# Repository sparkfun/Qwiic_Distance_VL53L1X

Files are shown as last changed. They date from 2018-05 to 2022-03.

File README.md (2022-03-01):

SparkFun Qwiic 4m Distance Sensor with VL53L1X
========================================

SparkFun Distance Sensor Breakout - 4 Meter, VL53L1X (Qwiic)

[*SparkFun Distance Sensor Breakout - 4 Meter, VL53L1X (Qwiic)(SEN-14722)*](https://www.sparkfun.com/products/14722)

The VL53L1X is the latest Time Of Flight (ToF) sensor to be released. It uses a VCSEL (vertical cavity surface emitting laser) to emit a class 1 IR laser and time the reflection to the target. What does all this mean? You can measure the distance to an object up to 4 meters away with millimeter resolution! That’s pretty incredible.

We’re far from done: The VL53L1X is a highly complex sensor with a multitude of options and configurations. We’ve written example sketches that allow you to read the distance, signal rate, and range status. Because ST has chosen not to release a complete datasheet we are forced to reverse engineer the interface from their example code and I2C data stream captures. If you’re into puzzles we could use your help to make the library better!

We’ve found the precision of the sensor to be 1mm but the accuracy is around +/-5mm.

SparkFun labored with love to create this code. Feel like supporting open source hardware? 
Buy a [breakout board](https://www.sparkfun.com/products/14722) from SparkFun!

Repository Contents
-------------------

* **/Documents** - Datasheet and User Manual
* **/Hardware** - Eagle design files (.brd, .sch)
* **/Production** - .brd files

Documentation
--------------
* **[Arduino Library](https://github.com/sparkfun/SparkFun_VL53L1X_Arduino_Library)** - Library for reading distance in millimeters, signal rate, status, etc.
* **[Hookup Guide](https://learn.sparkfun.com/tutorials/qwiic-distance-sensor-vl53l1x-vl53l4cd-hookup-guide)** - Basic hookup guide for the VL53L1X and VL53L4CD.

Product Versions
--------------
* **[SEN-14722](https://www.sparkfun.com/products/14722)** - SparkFun red version
* **[SPX-14667](https://www.sparkfun.com/products/14667)** - SparkX Version 

License Information
-------------------

This product is _**open source**_! 

Please review the LICENSE.md file for license information. 

If you have any questions or concerns on licensing, please contact techsupport@sparkfun.com.

Please use, reuse, and modify these files as you see fit. Please maintain attribution to SparkFun Electronics and release any derivative under the same license.

Distributed as-is; no warranty is given.

- Your friends at SparkFun.

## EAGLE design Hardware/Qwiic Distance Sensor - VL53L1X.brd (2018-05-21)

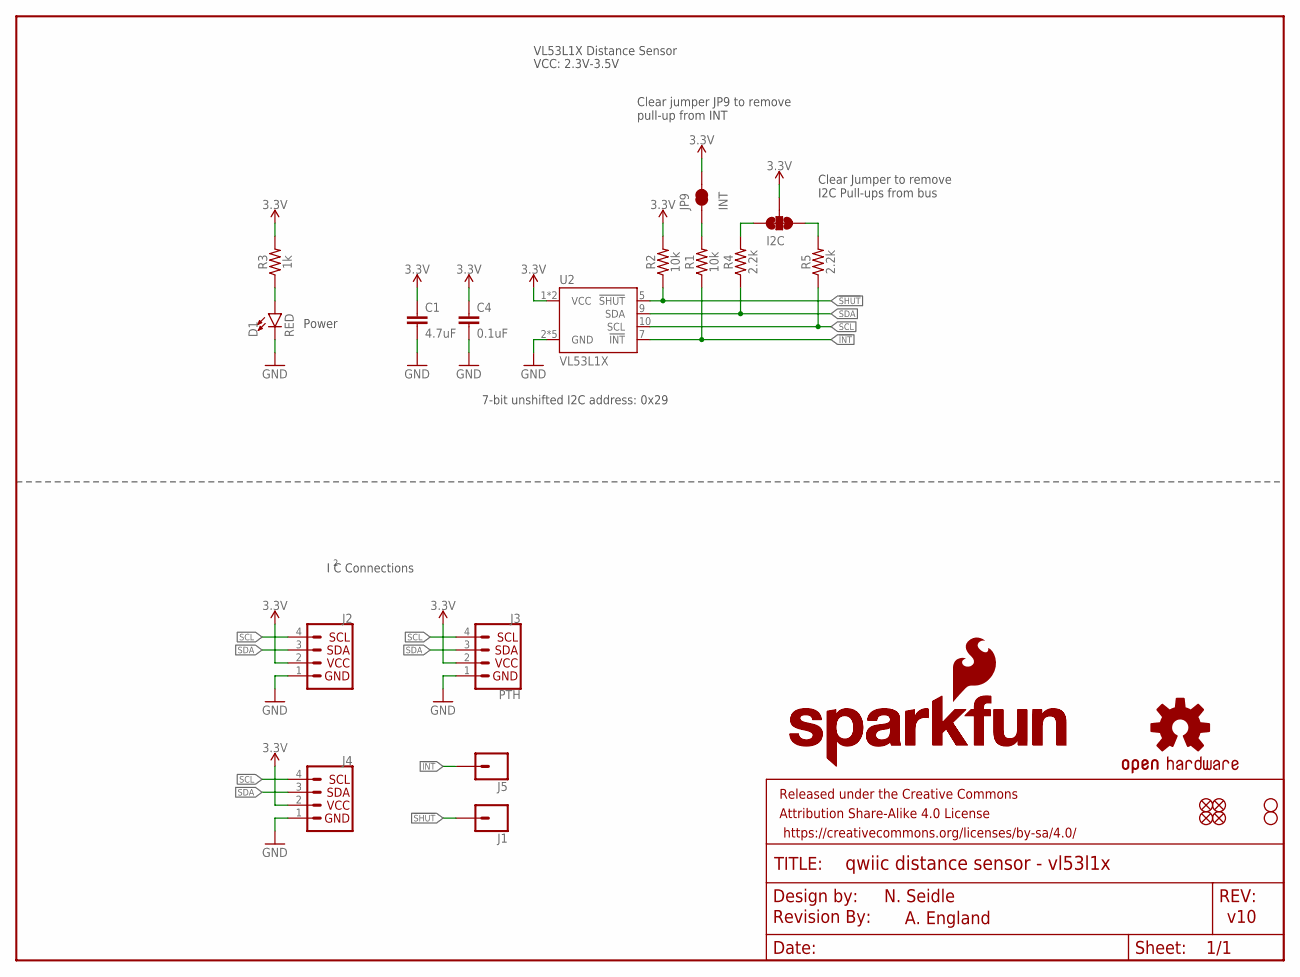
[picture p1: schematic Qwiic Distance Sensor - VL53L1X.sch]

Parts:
C1: 4.7uF; 0603
C4: 0.1uF; 0603
D1: RED; LED-0603
FRAME1: FRAME-LETTER; CREATIVE_COMMONS
I2C: JUMPER-SMT_3_2-NC_TRACE_SILK; SMT-JUMPER_3_2-NC_TRACE_SILK
J1, J5: CONN_01PTH_NO_SILK_YES_STOP; 1X01_NO_SILK
J2, J4: QWIIC_CONNECTORJS-1MM; 1X04_1MM_RA
J3: PTH; 1X04_NO_SILK
JP1, JP2, JP5, JP6: FIDUCIALUFIDUCIAL; MICRO-FIDUCIAL
JP3, JP4: STAND-OFF
JP9: INT; PAD-JUMPER-2-NC_BY_TRACE_YES_SILK
LOGO1: OSHW-LOGOMINI; OSHW-LOGO-MINI
LOGO2: REVISION
R1, R2: 10k; 0603
R3: 1k; 0603
R4, R5: 2.2k; 0603
U2: VL53L1X
U$1: SFE_LOGO_NAME.1_INCH; SFE_LOGO_NAME_.1
U$2: SFE_LOGO_NAME_FLAME.1_INCH; SFE_LOGO_NAME_FLAME_.1

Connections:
3.3V: C1.1, C4.1, I2C.2, J2.2, J3.2 (VCC), J4.2, JP9.2, R2.2, R3.2, U2.1 (VCC), U2.11 (VCC)
!INT: J5.1, R1.1, U2.7 (!INT)
!SHUT: J1.1, R2.1, U2.5 (!SHUT)
GND: C1.2, C4.2, D1.C, J2.1, J3.1 (GND), J4.1, U2.2 (GND), U2.3 (GND), U2.4 (GND), U2.6 (GND), U2.12 (GND)
unnamed: I2C.1, R5.2
unnamed: I2C.3, R4.2
unnamed: D1.A, R3.1
unnamed: JP9.1, R1.2
SCL: J2.4, J3.4 (SCL), J4.4, R5.1, U2.10 (SCL)
SDA: J2.3, J3.3 (SDA), J4.3, R4.1, U2.9 (SDA)

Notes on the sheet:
N. Seidle
v10
7-bit unshifted I2C address: 0x29
Clear Jumper to remove I2C Pull-ups from bus
Clear jumper JP9 to remove pull-up from INT
Power
A. England
I C Connections
VL53L1X Distance Sensor
VCC: 2.3V-3.5V

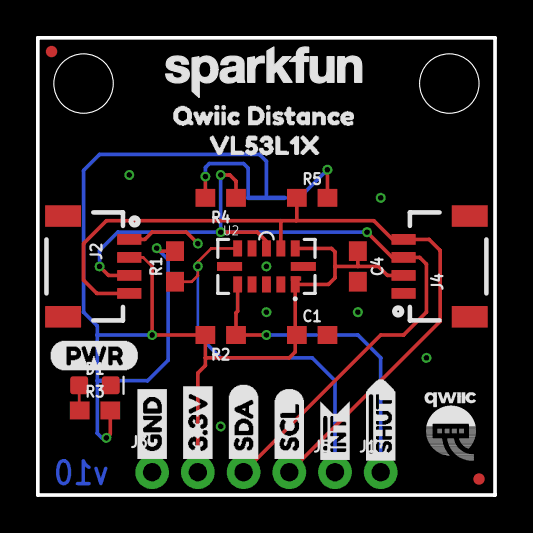
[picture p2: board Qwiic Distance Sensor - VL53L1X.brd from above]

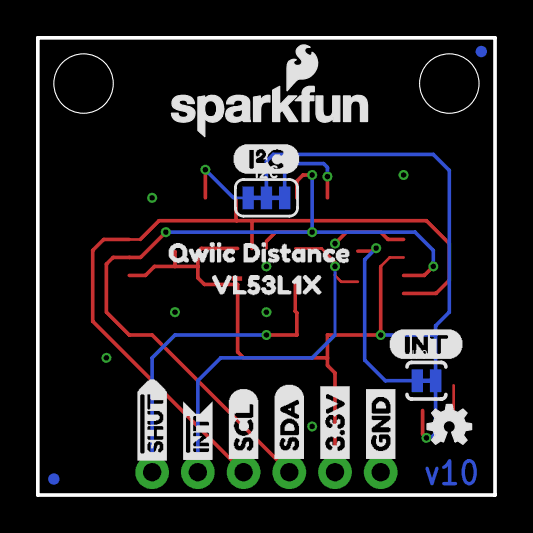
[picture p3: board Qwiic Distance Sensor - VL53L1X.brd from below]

Board: 2 copper layers, 25.4 x 25.4 mm, 47 parts (16 on the bottom side), 10 nets.

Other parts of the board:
U$3, U$22: GND1
U$4, U$21: 3#3V2
U$5, U$27: SDA8
U$6, U$26: SCL9
U$7, U$14: INT#-[<
U$8, U$9: #SHUT15
U$10: (PWR)
U$11: (I_SUPER2_C)
U$12: (INT)
U$13: QWIIC-LOGO-SMALL
U$15, U$19: QWIIC_DISTANCE0
U$16, U$20: VL53L1X1

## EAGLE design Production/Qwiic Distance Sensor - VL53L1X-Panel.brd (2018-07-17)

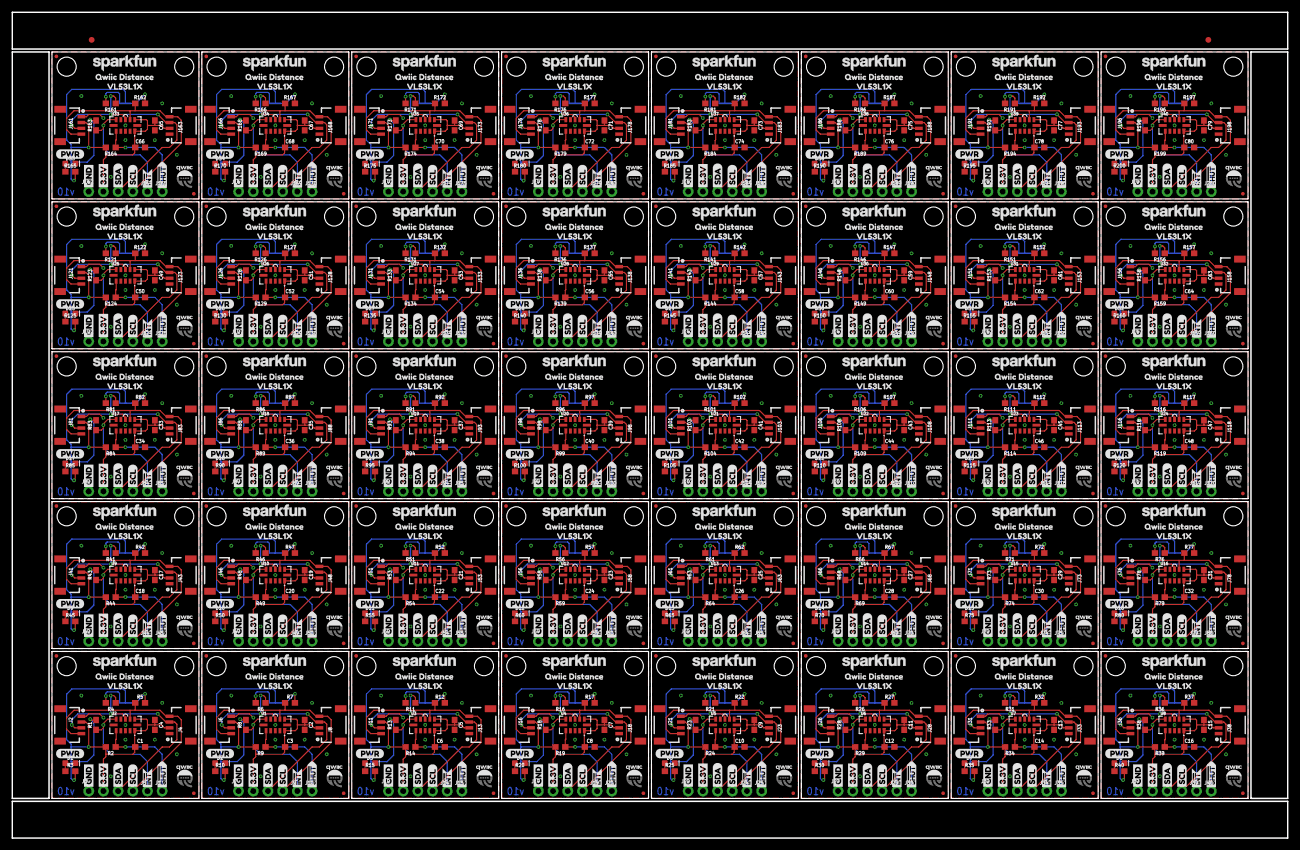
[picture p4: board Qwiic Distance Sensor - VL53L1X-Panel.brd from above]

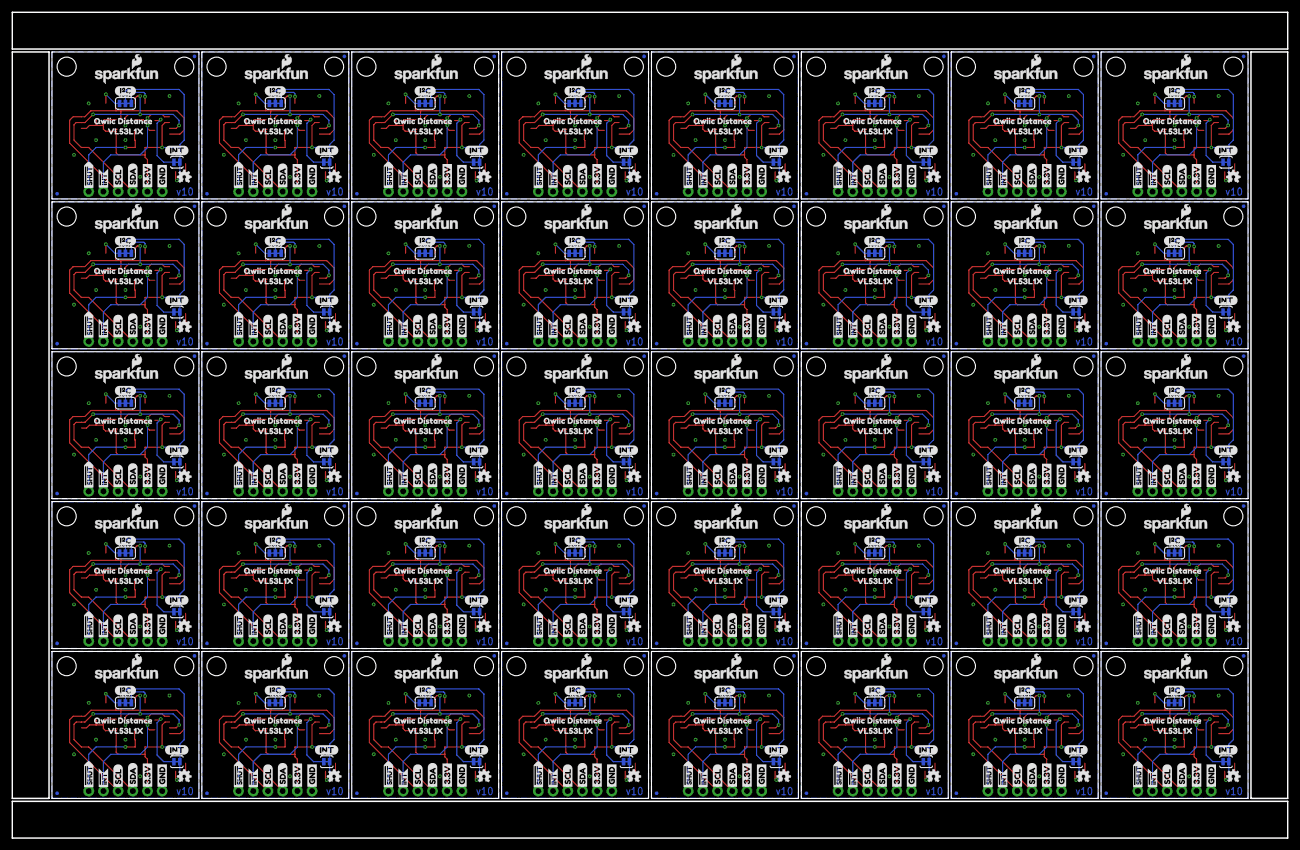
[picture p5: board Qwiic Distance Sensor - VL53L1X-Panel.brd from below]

Board: 2 copper layers, 220.5 x 142.7 mm, 1802 parts (640 on the bottom side), 400 nets.

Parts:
C1, C3, C6, C8, C10, C12, C14, C16, C18, C20, C22, C24, C26, C28, C30, C32, C34, C36, C38, C40, C42, C44, C46, C48, C50, C52, C54, C56, C58, C60, C62, C64, C66, C68, C70, C72, C74, C76, C78, C80: 4.7uF; 0603
C2, C4, C5, C7, C9, C11, C13, C15, C17, C19, C21, C23, C25, C27, C29, C31, C33, C35, C37, C39, C41, C43, C45, C47, C49, C51, C53, C55, C57, C59, C61, C63, C65, C67, C69, C71, C73, C75, C77, C79: 0.1uF; 0603
D1, D2, D3, D4, D5, D6, D7, D8, D9, D10, D11, D12, D13, D14, D15, D16, D17, D18, D19, D20, D21, D22, D23, D24, D25, D26, D27, D28, D29, D30, D31, D32, D33, D34, D35, D36, D37, D38, D39, D40: RED; LED-0603
E$1, E$2: FIDUCIAL-1X2
I2C, I2C1, I2C2, I2C3, I2C4, I2C5, I2C6, I2C7, I2C8, I2C9, I2C10, I2C11, I2C12, I2C13, I2C14, I2C15, I2C16, I2C17, I2C18, I2C19, I2C20, I2C21, I2C22, I2C23, I2C24, I2C25, I2C26, I2C27, I2C28, I2C29, I2C30, I2C31, I2C32, I2C33, I2C34, I2C35, I2C36, I2C37, I2C38, I2C39: SMT-JUMPER_3_2-NC_TRACE_SILK
J1, J5, J9, J10, J14, J15, J19, J20, J24, J25, J29, J30, J34, J35, J39, J40, J44, J45, J49, J50, J54, J55, J59, J60, J64, J65, J69, J70, J74, J75, J79, J80, J84, J85, J89, J90, J94, J95, J99, J100, J104, J105, J109, J110, J114, J115, J119, J120, J124, J125, J129, J130, J134, J135, J139, J140, J144, J145, J149, J150, J154, J155, J159, J160, J164, J165, J169, J170, J174, J175, J179, J180, J184, J185, J189, J190, J194, J195, J199, J200: 1X01_NO_SILK
J2, J4, J6, J8, J11, J13, J16, J18, J21, J23, J26, J28, J31, J33, J36, J38, J41, J43, J46, J48, J51, J53, J56, J58, J61, J63, J66, J68, J71, J73, J76, J78, J81, J83, J86, J88, J91, J93, J96, J98, J101, J103, J106, J108, J111, J113, J116, J118, J121, J123, J126, J128, J131, J133, J136, J138, J141, J143, J146, J148, J151, J153, J156, J158, J161, J163, J166, J168, J171, J173, J176, J178, J181, J183, J186, J188, J191, J193, J196, J198: 1X04_1MM_RA
J3, J7, J12, J17, J22, J27, J32, J37, J42, J47, J52, J57, J62, J67, J72, J77, J82, J87, J92, J97, J102, J107, J112, J117, J122, J127, J132, J137, J142, J147, J152, J157, J162, J167, J172, J177, J182, J187, J192, J197: PTH; 1X04_NO_SILK
JP1, JP2, JP5, JP6, JP10, JP11, JP12, JP13, JP17, JP18, JP19, JP20, JP24, JP25, JP26, JP27, JP31, JP32, JP33, JP34, JP38, JP39, JP40, JP41, JP45, JP46, JP47, JP48, JP52, JP53, JP54, JP55, JP59, JP60, JP61, JP62, JP66, JP67, JP68, JP69, JP73, JP74, JP75, JP76, JP80, JP81, JP82, JP83, JP87, JP88, JP89, JP90, JP94, JP95, JP96, JP97, JP101, JP102, JP103, JP104, JP108, JP109, JP110, JP111, JP115, JP116, JP117, JP118, JP122, JP123, JP124, JP125, JP129, JP130, JP131, JP132, JP136, JP137, JP138, JP139, JP143, JP144, JP145, JP146, JP150, JP151, JP152, JP153, JP157, JP158, JP159, JP160, JP164, JP165, JP166, JP167, JP171, JP172, JP173, JP174, JP178, JP179, JP180, JP181, JP185, JP186, JP187, JP188, JP192, JP193, JP194, JP195, JP199, JP200, JP201, JP202, JP206, JP207, JP208, JP209, JP213, JP214, JP215, JP216, JP220, JP221, JP222, JP223, JP227, JP228, JP229, JP230, JP234, JP235, JP236, JP237, JP241, JP242, JP243, JP244, JP248, JP249, JP250, JP251, JP255, JP256, JP257, JP258, JP262, JP263, JP264, JP265, JP269, JP270, JP271, JP272, JP276, JP277, JP278, JP279: FIDUCIALUFIDUCIAL; MICRO-FIDUCIAL
JP3, JP4, JP7, JP8, JP15, JP16, JP22, JP23, JP29, JP30, JP36, JP37, JP43, JP44, JP50, JP51, JP57, JP58, JP64, JP65, JP71, JP72, JP78, JP79, JP85, JP86, JP92, JP93, JP99, JP100, JP106, JP107, JP113, JP114, JP120, JP121, JP127, JP128, JP134, JP135, JP141, JP142, JP148, JP149, JP155, JP156, JP162, JP163, JP169, JP170, JP176, JP177, JP183, JP184, JP190, JP191, JP197, JP198, JP204, JP205, JP211, JP212, JP218, JP219, JP225, JP226, JP232, JP233, JP239, JP240, JP246, JP247, JP253, JP254, JP260, JP261, JP267, JP268, JP274, JP275: STAND-OFF
JP9, JP14, JP21, JP28, JP35, JP42, JP49, JP56, JP63, JP70, JP77, JP84, JP91, JP98, JP105, JP112, JP119, JP126, JP133, JP140, JP147, JP154, JP161, JP168, JP175, JP182, JP189, JP196, JP203, JP210, JP217, JP224, JP231, JP238, JP245, JP252, JP259, JP266, JP273, JP280: INT; PAD-JUMPER-2-NC_BY_TRACE_YES_SILK
LOGO1, LOGO2, LOGO3, LOGO4, LOGO5, LOGO6, LOGO7, LOGO8, LOGO9, LOGO10, LOGO11, LOGO12, LOGO13, LOGO14, LOGO15, LOGO16, LOGO17, LOGO18, LOGO19, LOGO20, LOGO21, LOGO22, LOGO23, LOGO24, LOGO25, LOGO26, LOGO27, LOGO28, LOGO29, LOGO30, LOGO31, LOGO32, LOGO33, LOGO34, LOGO35, LOGO36, LOGO37, LOGO38, LOGO39, LOGO40: OSHW-LOGOMINI; OSHW-LOGO-MINI
R1, R2, R8, R9, R13, R14, R18, R19, R23, R24, R28, R29, R33, R34, R38, R39, R43, R44, R48, R49, R53, R54, R58, R59, R63, R64, R68, R69, R73, R74, R78, R79, R83, R84, R88, R89, R93, R94, R98, R99, R103, R104, R108, R109, R113, R114, R118, R119, R123, R124, R128, R129, R133, R134, R138, R139, R143, R144, R148, R149, R153, R154, R158, R159, R163, R164, R168, R169, R173, R174, R178, R179, R183, R184, R188, R189, R193, R194, R198, R199: 10k; 0603
R3, R10, R15, R20, R25, R30, R35, R40, R45, R50, R55, R60, R65, R70, R75, R80, R85, R90, R95, R100, R105, R110, R115, R120, R125, R130, R135, R140, R145, R150, R155, R160, R165, R170, R175, R180, R185, R190, R195, R200: 1k; 0603
R4, R5, R6, R7, R11, R12, R16, R17, R21, R22, R26, R27, R31, R32, R36, R37, R41, R42, R46, R47, R51, R52, R56, R57, R61, R62, R66, R67, R71, R72, R76, R77, R81, R82, R86, R87, R91, R92, R96, R97, R101, R102, R106, R107, R111, R112, R116, R117, R121, R122, R126, R127, R131, R132, R136, R137, R141, R142, R146, R147, R151, R152, R156, R157, R161, R162, R166, R167, R171, R172, R176, R177, R181, R182, R186, R187, R191, R192, R196, R197: 2.2k; 0603
U1, U2, U3, U4, U5, U6, U7, U8, U9, U10, U11, U12, U13, U14, U15, U16, U17, U18, U19, U20, U21, U22, U23, U24, U25, U26, U27, U28, U29, U30, U31, U32, U33, U34, U35, U36, U37, U38, U39, U40: VL53L1X
U$1, U$18, U$46, U$68, U$90, U$112, U$134, U$156, U$178, U$200, U$222, U$244, U$266, U$288, U$310, U$332, U$354, U$376, U$398, U$420, U$442, U$464, U$486, U$508, U$530, U$552, U$574, U$596, U$618, U$640, U$662, U$684, U$706, U$728, U$750, U$772, U$794, U$816, U$838, U$860: SFE_LOGO_NAME.1_INCH; SFE_LOGO_NAME_.1
U$2, U$17, U$45, U$67, U$89, U$111, U$133, U$155, U$177, U$199, U$221, U$243, U$265, U$287, U$309, U$331, U$353, U$375, U$397, U$419, U$441, U$463, U$485, U$507, U$529, U$551, U$573, U$595, U$617, U$639, U$661, U$683, U$705, U$727, U$749, U$771, U$793, U$815, U$837, U$859: SFE_LOGO_NAME_FLAME.1_INCH; SFE_LOGO_NAME_FLAME_.1
U$3, U$22, U$30, U$33, U$52, U$55, U$74, U$77, U$96, U$99, U$118, U$121, U$140, U$143, U$162, U$165, U$184, U$187, U$206, U$209, U$228, U$231, U$250, U$253, U$272, U$275, U$294, U$297, U$316, U$319, U$338, U$341, U$360, U$363, U$382, U$385, U$404, U$407, U$426, U$429, U$448, U$451, U$470, U$473, U$492, U$495, U$514, U$517, U$536, U$539, U$558, U$561, U$580, U$583, U$602, U$605, U$624, U$627, U$646, U$649, U$668, U$671, U$690, U$693, U$712, U$715, U$734, U$737, U$756, U$759, U$778, U$781, U$800, U$803, U$822, U$825, U$844, U$847, U$866, U$869: GND1
U$4, U$21, U$29, U$34, U$51, U$56, U$73, U$78, U$95, U$100, U$117, U$122, U$139, U$144, U$161, U$166, U$183, U$188, U$205, U$210, U$227, U$232, U$249, U$254, U$271, U$276, U$293, U$298, U$315, U$320, U$337, U$342, U$359, U$364, U$381, U$386, U$403, U$408, U$425, U$430, U$447, U$452, U$469, U$474, U$491, U$496, U$513, U$518, U$535, U$540, U$557, U$562, U$579, U$584, U$601, U$606, U$623, U$628, U$645, U$650, U$667, U$672, U$689, U$694, U$711, U$716, U$733, U$738, U$755, U$760, U$777, U$782, U$799, U$804, U$821, U$826, U$843, U$848, U$865, U$870: 3#3V2
U$5, U$27, U$32, U$35, U$54, U$57, U$76, U$79, U$98, U$101, U$120, U$123, U$142, U$145, U$164, U$167, U$186, U$189, U$208, U$211, U$230, U$233, U$252, U$255, U$274, U$277, U$296, U$299, U$318, U$321, U$340, U$343, U$362, U$365, U$384, U$387, U$406, U$409, U$428, U$431, U$450, U$453, U$472, U$475, U$494, U$497, U$516, U$519, U$538, U$541, U$560, U$563, U$582, U$585, U$604, U$607, U$626, U$629, U$648, U$651, U$670, U$673, U$692, U$695, U$714, U$717, U$736, U$739, U$758, U$761, U$780, U$783, U$802, U$805, U$824, U$827, U$846, U$849, U$868, U$871: SDA8
U$6, U$26, U$31, U$36, U$53, U$58, U$75, U$80, U$97, U$102, U$119, U$124, U$141, U$146, U$163, U$168, U$185, U$190, U$207, U$212, U$229, U$234, U$251, U$256, U$273, U$278, U$295, U$300, U$317, U$322, U$339, U$344, U$361, U$366, U$383, U$388, U$405, U$410, U$427, U$432, U$449, U$454, U$471, U$476, U$493, U$498, U$515, U$520, U$537, U$542, U$559, U$564, U$581, U$586, U$603, U$608, U$625, U$630, U$647, U$652, U$669, U$674, U$691, U$696, U$713, U$718, U$735, U$740, U$757, U$762, U$779, U$784, U$801, U$806, U$823, U$828, U$845, U$850, U$867, U$872: SCL9
U$7, U$14, U$43, U$44, U$65, U$66, U$87, U$88, U$109, U$110, U$131, U$132, U$153, U$154, U$175, U$176, U$197, U$198, U$219, U$220, U$241, U$242, U$263, U$264, U$285, U$286, U$307, U$308, U$329, U$330, U$351, U$352, U$373, U$374, U$395, U$396, U$417, U$418, U$439, U$440, U$461, U$462, U$483, U$484, U$505, U$506, U$527, U$528, U$549, U$550, U$571, U$572, U$593, U$594, U$615, U$616, U$637, U$638, U$659, U$660, U$681, U$682, U$703, U$704, U$725, U$726, U$747, U$748, U$769, U$770, U$791, U$792, U$813, U$814, U$835, U$836, U$857, U$858, U$879, U$880: INT#-[<
U$8, U$9, U$37, U$38, U$59, U$60, U$81, U$82, U$103, U$104, U$125, U$126, U$147, U$148, U$169, U$170, U$191, U$192, U$213, U$214, U$235, U$236, U$257, U$258, U$279, U$280, U$301, U$302, U$323, U$324, U$345, U$346, U$367, U$368, U$389, U$390, U$411, U$412, U$433, U$434, U$455, U$456, U$477, U$478, U$499, U$500, U$521, U$522, U$543, U$544, U$565, U$566, U$587, U$588, U$609, U$610, U$631, U$632, U$653, U$654, U$675, U$676, U$697, U$698, U$719, U$720, U$741, U$742, U$763, U$764, U$785, U$786, U$807, U$808, U$829, U$830, U$851, U$852, U$873, U$874: #SHUT15
U$10, U$39, U$61, U$83, U$105, U$127, U$149, U$171, U$193, U$215, U$237, U$259, U$281, U$303, U$325, U$347, U$369, U$391, U$413, U$435, U$457, U$479, U$501, U$523, U$545, U$567, U$589, U$611, U$633, U$655, U$677, U$699, U$721, U$743, U$765, U$787, U$809, U$831, U$853, U$875: (PWR)
U$11, U$40, U$62, U$84, U$106, U$128, U$150, U$172, U$194, U$216, U$238, U$260, U$282, U$304, U$326, U$348, U$370, U$392, U$414, U$436, U$458, U$480, U$502, U$524, U$546, U$568, U$590, U$612, U$634, U$656, U$678, U$700, U$722, U$744, U$766, U$788, U$810, U$832, U$854, U$876: (I_SUPER2_C)
U$12, U$41, U$63, U$85, U$107, U$129, U$151, U$173, U$195, U$217, U$239, U$261, U$283, U$305, U$327, U$349, U$371, U$393, U$415, U$437, U$459, U$481, U$503, U$525, U$547, U$569, U$591, U$613, U$635, U$657, U$679, U$701, U$723, U$745, U$767, U$789, U$811, U$833, U$855, U$877: (INT)
U$13, U$42, U$64, U$86, U$108, U$130, U$152, U$174, U$196, U$218, U$240, U$262, U$284, U$306, U$328, U$350, U$372, U$394, U$416, U$438, U$460, U$482, U$504, U$526, U$548, U$570, U$592, U$614, U$636, U$658, U$680, U$702, U$724, U$746, U$768, U$790, U$812, U$834, U$856, U$878: QWIIC-LOGO-SMALL
U$15, U$19, U$23, U$25, U$47, U$49, U$69, U$71, U$91, U$93, U$113, U$115, U$135, U$137, U$157, U$159, U$179, U$181, U$201, U$203, U$223, U$225, U$245, U$247, U$267, U$269, U$289, U$291, U$311, U$313, U$333, U$335, U$355, U$357, U$377, U$379, U$399, U$401, U$421, U$423, U$443, U$445, U$465, U$467, U$487, U$489, U$509, U$511, U$531, U$533, U$553, U$555, U$575, U$577, U$597, U$599, U$619, U$621, U$641, U$643, U$663, U$665, U$685, U$687, U$707, U$709, U$729, U$731, U$751, U$753, U$773, U$775, U$795, U$797, U$817, U$819, U$839, U$841, U$861, U$863: QWIIC_DISTANCE0
U$16, U$20, U$24, U$28, U$48, U$50, U$70, U$72, U$92, U$94, U$114, U$116, U$136, U$138, U$158, U$160, U$180, U$182, U$202, U$204, U$224, U$226, U$246, U$248, U$268, U$270, U$290, U$292, U$312, U$314, U$334, U$336, U$356, U$358, U$378, U$380, U$400, U$402, U$422, U$424, U$444, U$446, U$466, U$468, U$488, U$490, U$510, U$512, U$532, U$534, U$554, U$556, U$576, U$578, U$598, U$600, U$620, U$622, U$642, U$644, U$664, U$666, U$686, U$688, U$708, U$710, U$730, U$732, U$752, U$754, U$774, U$776, U$796, U$798, U$818, U$820, U$840, U$842, U$862, U$864: VL53L1X1

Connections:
3.3V: C1.1, C4.1, I2C.2, J2.2, J3.2, J4.2, JP9.2, R2.2, R3.2, U2.1, U2.11
3.3V1: C2.1, C3.1, I2C1.2, J6.2, J7.2, J8.2, JP14.2, R9.2, R10.2, U1.1, U1.11
3.3V2: C5.1, C6.1, I2C2.2, J11.2, J12.2, J13.2, JP21.2, R14.2, R15.2, U3.1, U3.11
3.3V3: C7.1, C8.1, I2C3.2, J16.2, J17.2, J18.2, JP28.2, R19.2, R20.2, U4.1, U4.11
3.3V4: C9.1, C10.1, I2C4.2, J21.2, J22.2, J23.2, JP35.2, R24.2, R25.2, U5.1, U5.11
3.3V5: C11.1, C12.1, I2C5.2, J26.2, J27.2, J28.2, JP42.2, R29.2, R30.2, U6.1, U6.11
3.3V6: C13.1, C14.1, I2C6.2, J31.2, J32.2, J33.2, JP49.2, R34.2, R35.2, U7.1, U7.11
3.3V7: C15.1, C16.1, I2C7.2, J36.2, J37.2, J38.2, JP56.2, R39.2, R40.2, U8.1, U8.11
3.3V8: C17.1, C18.1, I2C8.2, J41.2, J42.2, J43.2, JP63.2, R44.2, R45.2, U9.1, U9.11
3.3V9: C19.1, C20.1, I2C9.2, J46.2, J47.2, J48.2, JP70.2, R49.2, R50.2, U10.1, U10.11
3.3V10: C21.1, C22.1, I2C10.2, J51.2, J52.2, J53.2, JP77.2, R54.2, R55.2, U11.1, U11.11
3.3V11: C23.1, C24.1, I2C11.2, J56.2, J57.2, J58.2, JP84.2, R59.2, R60.2, U12.1, U12.11
3.3V12: C25.1, C26.1, I2C12.2, J61.2, J62.2, J63.2, JP91.2, R64.2, R65.2, U13.1, U13.11
3.3V13: C27.1, C28.1, I2C13.2, J66.2, J67.2, J68.2, JP98.2, R69.2, R70.2, U14.1, U14.11
3.3V14: C29.1, C30.1, I2C14.2, J71.2, J72.2, J73.2, JP105.2, R74.2, R75.2, U15.1, U15.11
3.3V15: C31.1, C32.1, I2C15.2, J76.2, J77.2, J78.2, JP112.2, R79.2, R80.2, U16.1, U16.11
3.3V16: C33.1, C34.1, I2C16.2, J81.2, J82.2, J83.2, JP119.2, R84.2, R85.2, U17.1, U17.11
3.3V17: C35.1, C36.1, I2C17.2, J86.2, J87.2, J88.2, JP126.2, R89.2, R90.2, U18.1, U18.11
3.3V18: C37.1, C38.1, I2C18.2, J91.2, J92.2, J93.2, JP133.2, R94.2, R95.2, U19.1, U19.11
3.3V19: C39.1, C40.1, I2C19.2, J96.2, J97.2, J98.2, JP140.2, R99.2, R100.2, U20.1, U20.11
3.3V20: C41.1, C42.1, I2C20.2, J101.2, J102.2, J103.2, JP147.2, R104.2, R105.2, U21.1, U21.11
3.3V21: C43.1, C44.1, I2C21.2, J106.2, J107.2, J108.2, JP154.2, R109.2, R110.2, U22.1, U22.11
3.3V22: C45.1, C46.1, I2C22.2, J111.2, J112.2, J113.2, JP161.2, R114.2, R115.2, U23.1, U23.11
3.3V23: C47.1, C48.1, I2C23.2, J116.2, J117.2, J118.2, JP168.2, R119.2, R120.2, U24.1, U24.11
3.3V24: C49.1, C50.1, I2C24.2, J121.2, J122.2, J123.2, JP175.2, R124.2, R125.2, U25.1, U25.11
3.3V25: C51.1, C52.1, I2C25.2, J126.2, J127.2, J128.2, JP182.2, R129.2, R130.2, U26.1, U26.11
3.3V26: C53.1, C54.1, I2C26.2, J131.2, J132.2, J133.2, JP189.2, R134.2, R135.2, U27.1, U27.11
3.3V27: C55.1, C56.1, I2C27.2, J136.2, J137.2, J138.2, JP196.2, R139.2, R140.2, U28.1, U28.11
3.3V28: C57.1, C58.1, I2C28.2, J141.2, J142.2, J143.2, JP203.2, R144.2, R145.2, U29.1, U29.11
3.3V29: C59.1, C60.1, I2C29.2, J146.2, J147.2, J148.2, JP210.2, R149.2, R150.2, U30.1, U30.11
3.3V30: C61.1, C62.1, I2C30.2, J151.2, J152.2, J153.2, JP217.2, R154.2, R155.2, U31.1, U31.11
3.3V31: C63.1, C64.1, I2C31.2, J156.2, J157.2, J158.2, JP224.2, R159.2, R160.2, U32.1, U32.11
3.3V32: C65.1, C66.1, I2C32.2, J161.2, J162.2, J163.2, JP231.2, R164.2, R165.2, U33.1, U33.11
3.3V33: C67.1, C68.1, I2C33.2, J166.2, J167.2, J168.2, JP238.2, R169.2, R170.2, U34.1, U34.11
3.3V34: C69.1, C70.1, I2C34.2, J171.2, J172.2, J173.2, JP245.2, R174.2, R175.2, U35.1, U35.11
3.3V35: C71.1, C72.1, I2C35.2, J176.2, J177.2, J178.2, JP252.2, R179.2, R180.2, U36.1, U36.11
3.3V36: C73.1, C74.1, I2C36.2, J181.2, J182.2, J183.2, JP259.2, R184.2, R185.2, U37.1, U37.11
3.3V37: C75.1, C76.1, I2C37.2, J186.2, J187.2, J188.2, JP266.2, R189.2, R190.2, U38.1, U38.11
3.3V38: C77.1, C78.1, I2C38.2, J191.2, J192.2, J193.2, JP273.2, R194.2, R195.2, U39.1, U39.11
3.3V39: C79.1, C80.1, I2C39.2, J196.2, J197.2, J198.2, JP280.2, R199.2, R200.2, U40.1, U40.11
!INT: J5.1, R1.1, U2.7
!INT1: J9.1, R8.1, U1.7
!INT2: J14.1, R13.1, U3.7
!INT3: J19.1, R18.1, U4.7
!INT4: J24.1, R23.1, U5.7
!INT5: J29.1, R28.1, U6.7
!INT6: J34.1, R33.1, U7.7
!INT7: J39.1, R38.1, U8.7
!INT8: J44.1, R43.1, U9.7
!INT9: J49.1, R48.1, U10.7
!INT10: J54.1, R53.1, U11.7
!INT11: J59.1, R58.1, U12.7
!INT12: J64.1, R63.1, U13.7
!INT13: J69.1, R68.1, U14.7
!INT14: J74.1, R73.1, U15.7
!INT15: J79.1, R78.1, U16.7
!INT16: J84.1, R83.1, U17.7
!INT17: J89.1, R88.1, U18.7
!INT18: J94.1, R93.1, U19.7
!INT19: J99.1, R98.1, U20.7
!INT20: J104.1, R103.1, U21.7
!INT21: J109.1, R108.1, U22.7
!INT22: J114.1, R113.1, U23.7
!INT23: J119.1, R118.1, U24.7
!INT24: J124.1, R123.1, U25.7
!INT25: J129.1, R128.1, U26.7
!INT26: J134.1, R133.1, U27.7
!INT27: J139.1, R138.1, U28.7
!INT28: J144.1, R143.1, U29.7
!INT29: J149.1, R148.1, U30.7
!INT30: J154.1, R153.1, U31.7
!INT31: J159.1, R158.1, U32.7
!INT32: J164.1, R163.1, U33.7
!INT33: J169.1, R168.1, U34.7
!INT34: J174.1, R173.1, U35.7
!INT35: J179.1, R178.1, U36.7
!INT36: J184.1, R183.1, U37.7
!INT37: J189.1, R188.1, U38.7
!INT38: J194.1, R193.1, U39.7
!INT39: J199.1, R198.1, U40.7
!SHUT: J1.1, R2.1, U2.5
!SHUT1: J10.1, R9.1, U1.5
!SHUT2: J15.1, R14.1, U3.5
!SHUT3: J20.1, R19.1, U4.5
!SHUT4: J25.1, R24.1, U5.5
!SHUT5: J30.1, R29.1, U6.5
!SHUT6: J35.1, R34.1, U7.5
!SHUT7: J40.1, R39.1, U8.5
!SHUT8: J45.1, R44.1, U9.5
!SHUT9: J50.1, R49.1, U10.5
!SHUT10: J55.1, R54.1, U11.5
!SHUT11: J60.1, R59.1, U12.5
!SHUT12: J65.1, R64.1, U13.5
!SHUT13: J70.1, R69.1, U14.5
!SHUT14: J75.1, R74.1, U15.5
!SHUT15: J80.1, R79.1, U16.5
!SHUT16: J85.1, R84.1, U17.5
!SHUT17: J90.1, R89.1, U18.5
!SHUT18: J95.1, R94.1, U19.5
!SHUT19: J100.1, R99.1, U20.5
!SHUT20: J105.1, R104.1, U21.5
!SHUT21: J110.1, R109.1, U22.5
!SHUT22: J115.1, R114.1, U23.5
!SHUT23: J120.1, R119.1, U24.5
!SHUT24: J125.1, R124.1, U25.5
!SHUT25: J130.1, R129.1, U26.5
!SHUT26: J135.1, R134.1, U27.5
!SHUT27: J140.1, R139.1, U28.5
!SHUT28: J145.1, R144.1, U29.5
!SHUT29: J150.1, R149.1, U30.5
!SHUT30: J155.1, R154.1, U31.5
!SHUT31: J160.1, R159.1, U32.5
!SHUT32: J165.1, R164.1, U33.5
!SHUT33: J170.1, R169.1, U34.5
!SHUT34: J175.1, R174.1, U35.5
!SHUT35: J180.1, R179.1, U36.5
!SHUT36: J185.1, R184.1, U37.5
!SHUT37: J190.1, R189.1, U38.5
!SHUT38: J195.1, R194.1, U39.5
!SHUT39: J200.1, R199.1, U40.5
GND: C1.2, C4.2, D1.C, J2.1, J3.1, J4.1, U2.2, U2.3, U2.4, U2.6, U2.12
GND1: C2.2, C3.2, D2.C, J6.1, J7.1, J8.1, U1.2, U1.3, U1.4, U1.6, U1.12
GND2: C5.2, C6.2, D3.C, J11.1, J12.1, J13.1, U3.2, U3.3, U3.4, U3.6, U3.12
GND3: C7.2, C8.2, D4.C, J16.1, J17.1, J18.1, U4.2, U4.3, U4.4, U4.6, U4.12
GND4: C9.2, C10.2, D5.C, J21.1, J22.1, J23.1, U5.2, U5.3, U5.4, U5.6, U5.12
GND5: C11.2, C12.2, D6.C, J26.1, J27.1, J28.1, U6.2, U6.3, U6.4, U6.6, U6.12
GND6: C13.2, C14.2, D7.C, J31.1, J32.1, J33.1, U7.2, U7.3, U7.4, U7.6, U7.12
GND7: C15.2, C16.2, D8.C, J36.1, J37.1, J38.1, U8.2, U8.3, U8.4, U8.6, U8.12
GND8: C17.2, C18.2, D9.C, J41.1, J42.1, J43.1, U9.2, U9.3, U9.4, U9.6, U9.12
GND9: C19.2, C20.2, D10.C, J46.1, J47.1, J48.1, U10.2, U10.3, U10.4, U10.6, U10.12
GND10: C21.2, C22.2, D11.C, J51.1, J52.1, J53.1, U11.2, U11.3, U11.4, U11.6, U11.12
GND11: C23.2, C24.2, D12.C, J56.1, J57.1, J58.1, U12.2, U12.3, U12.4, U12.6, U12.12
GND12: C25.2, C26.2, D13.C, J61.1, J62.1, J63.1, U13.2, U13.3, U13.4, U13.6, U13.12
GND13: C27.2, C28.2, D14.C, J66.1, J67.1, J68.1, U14.2, U14.3, U14.4, U14.6, U14.12
GND14: C29.2, C30.2, D15.C, J71.1, J72.1, J73.1, U15.2, U15.3, U15.4, U15.6, U15.12
GND15: C31.2, C32.2, D16.C, J76.1, J77.1, J78.1, U16.2, U16.3, U16.4, U16.6, U16.12
GND16: C33.2, C34.2, D17.C, J81.1, J82.1, J83.1, U17.2, U17.3, U17.4, U17.6, U17.12
GND17: C35.2, C36.2, D18.C, J86.1, J87.1, J88.1, U18.2, U18.3, U18.4, U18.6, U18.12
GND18: C37.2, C38.2, D19.C, J91.1, J92.1, J93.1, U19.2, U19.3, U19.4, U19.6, U19.12
GND19: C39.2, C40.2, D20.C, J96.1, J97.1, J98.1, U20.2, U20.3, U20.4, U20.6, U20.12
GND20: C41.2, C42.2, D21.C, J101.1, J102.1, J103.1, U21.2, U21.3, U21.4, U21.6, U21.12
GND21: C43.2, C44.2, D22.C, J106.1, J107.1, J108.1, U22.2, U22.3, U22.4, U22.6, U22.12
GND22: C45.2, C46.2, D23.C, J111.1, J112.1, J113.1, U23.2, U23.3, U23.4, U23.6, U23.12
GND23: C47.2, C48.2, D24.C, J116.1, J117.1, J118.1, U24.2, U24.3, U24.4, U24.6, U24.12
GND24: C49.2, C50.2, D25.C, J121.1, J122.1, J123.1, U25.2, U25.3, U25.4, U25.6, U25.12
GND25: C51.2, C52.2, D26.C, J126.1, J127.1, J128.1, U26.2, U26.3, U26.4, U26.6, U26.12
GND26: C53.2, C54.2, D27.C, J131.1, J132.1, J133.1, U27.2, U27.3, U27.4, U27.6, U27.12
GND27: C55.2, C56.2, D28.C, J136.1, J137.1, J138.1, U28.2, U28.3, U28.4, U28.6, U28.12
GND28: C57.2, C58.2, D29.C, J141.1, J142.1, J143.1, U29.2, U29.3, U29.4, U29.6, U29.12
GND29: C59.2, C60.2, D30.C, J146.1, J147.1, J148.1, U30.2, U30.3, U30.4, U30.6, U30.12
GND30: C61.2, C62.2, D31.C, J151.1, J152.1, J153.1, U31.2, U31.3, U31.4, U31.6, U31.12
GND31: C63.2, C64.2, D32.C, J156.1, J157.1, J158.1, U32.2, U32.3, U32.4, U32.6, U32.12
GND32: C65.2, C66.2, D33.C, J161.1, J162.1, J163.1, U33.2, U33.3, U33.4, U33.6, U33.12
GND33: C67.2, C68.2, D34.C, J166.1, J167.1, J168.1, U34.2, U34.3, U34.4, U34.6, U34.12
GND34: C69.2, C70.2, D35.C, J171.1, J172.1, J173.1, U35.2, U35.3, U35.4, U35.6, U35.12
GND35: C71.2, C72.2, D36.C, J176.1, J177.1, J178.1, U36.2, U36.3, U36.4, U36.6, U36.12
GND36: C73.2, C74.2, D37.C, J181.1, J182.1, J183.1, U37.2, U37.3, U37.4, U37.6, U37.12
GND37: C75.2, C76.2, D38.C, J186.1, J187.1, J188.1, U38.2, U38.3, U38.4, U38.6, U38.12
GND38: C77.2, C78.2, D39.C, J191.1, J192.1, J193.1, U39.2, U39.3, U39.4, U39.6, U39.12
GND39: C79.2, C80.2, D40.C, J196.1, J197.1, J198.1, U40.2, U40.3, U40.4, U40.6, U40.12
unnamed: I2C.1, R5.2
unnamed: I2C.3, R4.2
unnamed: D1.A, R3.1
unnamed: JP9.1, R1.2
unnamed: I2C1.1, R7.2
unnamed: I2C1.3, R6.2
unnamed: JP14.1, R8.2
unnamed: D2.A, R10.1
unnamed: I2C2.1, R12.2
unnamed: I2C2.3, R11.2
unnamed: JP21.1, R13.2
unnamed: D3.A, R15.1
unnamed: I2C3.1, R17.2
unnamed: I2C3.3, R16.2
unnamed: JP28.1, R18.2
unnamed: D4.A, R20.1
unnamed: I2C4.1, R22.2
unnamed: I2C4.3, R21.2
unnamed: JP35.1, R23.2
unnamed: D5.A, R25.1
unnamed: I2C5.1, R27.2
unnamed: I2C5.3, R26.2
unnamed: JP42.1, R28.2
unnamed: D6.A, R30.1
unnamed: I2C6.1, R32.2
unnamed: I2C6.3, R31.2
unnamed: JP49.1, R33.2
unnamed: D7.A, R35.1
unnamed: I2C7.1, R37.2
unnamed: I2C7.3, R36.2
unnamed: JP56.1, R38.2
unnamed: D8.A, R40.1
unnamed: I2C8.1, R42.2
unnamed: I2C8.3, R41.2
unnamed: JP63.1, R43.2
unnamed: D9.A, R45.1
unnamed: I2C9.1, R47.2
unnamed: I2C9.3, R46.2
unnamed: JP70.1, R48.2
unnamed: D10.A, R50.1
unnamed: I2C10.1, R52.2
unnamed: I2C10.3, R51.2
unnamed: JP77.1, R53.2
unnamed: D11.A, R55.1
unnamed: I2C11.1, R57.2
unnamed: I2C11.3, R56.2
unnamed: JP84.1, R58.2
unnamed: D12.A, R60.1
unnamed: I2C12.1, R62.2
unnamed: I2C12.3, R61.2
unnamed: JP91.1, R63.2
unnamed: D13.A, R65.1
unnamed: I2C13.1, R67.2
unnamed: I2C13.3, R66.2
unnamed: JP98.1, R68.2
unnamed: D14.A, R70.1
unnamed: I2C14.1, R72.2
unnamed: I2C14.3, R71.2
unnamed: JP105.1, R73.2
unnamed: D15.A, R75.1
unnamed: I2C15.1, R77.2
unnamed: I2C15.3, R76.2
unnamed: JP112.1, R78.2
unnamed: D16.A, R80.1
unnamed: I2C16.1, R82.2
unnamed: I2C16.3, R81.2
unnamed: JP119.1, R83.2
unnamed: D17.A, R85.1
unnamed: I2C17.1, R87.2
unnamed: I2C17.3, R86.2
unnamed: JP126.1, R88.2
unnamed: D18.A, R90.1
unnamed: I2C18.1, R92.2
unnamed: I2C18.3, R91.2
unnamed: JP133.1, R93.2
unnamed: D19.A, R95.1
unnamed: I2C19.1, R97.2
unnamed: I2C19.3, R96.2
unnamed: JP140.1, R98.2
unnamed: D20.A, R100.1
unnamed: I2C20.1, R102.2
unnamed: I2C20.3, R101.2
unnamed: JP147.1, R103.2
unnamed: D21.A, R105.1
unnamed: I2C21.1, R107.2
unnamed: I2C21.3, R106.2
unnamed: JP154.1, R108.2
unnamed: D22.A, R110.1
unnamed: I2C22.1, R112.2
unnamed: I2C22.3, R111.2
unnamed: JP161.1, R113.2
unnamed: D23.A, R115.1
unnamed: I2C23.1, R117.2
unnamed: I2C23.3, R116.2
unnamed: JP168.1, R118.2
unnamed: D24.A, R120.1
unnamed: I2C24.1, R122.2
unnamed: I2C24.3, R121.2
unnamed: JP175.1, R123.2
unnamed: D25.A, R125.1
unnamed: I2C25.1, R127.2
unnamed: I2C25.3, R126.2
unnamed: JP182.1, R128.2
unnamed: D26.A, R130.1
unnamed: I2C26.1, R132.2
unnamed: I2C26.3, R131.2
unnamed: JP189.1, R133.2
unnamed: D27.A, R135.1
unnamed: I2C27.1, R137.2
unnamed: I2C27.3, R136.2
unnamed: JP196.1, R138.2
unnamed: D28.A, R140.1
unnamed: I2C28.1, R142.2
unnamed: I2C28.3, R141.2
unnamed: JP203.1, R143.2
unnamed: D29.A, R145.1
unnamed: I2C29.1, R147.2
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

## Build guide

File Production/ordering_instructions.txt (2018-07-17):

panel size, 221x143mm
PCB thickness, 1.6mm
number of layers, 2
soldermask color, Red
silkscreen color, White
oz copper, 1oz
finish, HASL lead free
stencils, top

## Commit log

2018-05-03 Moving to Reds
    [Qwiic Distance Sensor - VL53L1X.brd, Qwiic Distance Sensor - VL53L1X.sch]
2018-05-03 updated silk
    [Qwiic Distance Sensor - VL53L1X.brd]
2018-05-03 updating Qwiic connectors
    [Qwiic Distance Sensor - VL53L1X.brd, Qwiic Distance Sensor - VL53L1X.sch]
2018-05-14 changing INT silk
    [Qwiic Distance Sensor - VL53L1X.brd]
2018-05-14 post review changes
    [Qwiic Distance Sensor - VL53L1X.sch]
2018-05-21 Fixing issues
    [Qwiic Distance Sensor - VL53L1X.brd, Qwiic Distance Sensor - VL53L1X.sch]
2018-05-29 created panel v10
    [Qwiic Distance Sensor - VL53L1X-Panel_v10.brd]
2018-07-17 changed distance between boards for v-scoring
    [Qwiic Distance Sensor - VL53L1X-Panel.brd, Qwiic Distance Sensor - VL53L1X-Panel_v10.brd]
2020-06-24 x01 ordered
    Exact clone of VL53L1X Board with different silk
    [Qwiic Distance Sensor - VL53L1X-Panel.brd, Qwiic Distance Sensor - VL53L1X.brd, Qwiic Distance Sensor - VL53L1X.sch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]
2020-06-29 Revert "x01 ordered"
    This reverts commit 0e4841487b21f37b9834273fb5b77fccae1b5381.
    [Qwiic Distance Sensor - VL53L1X-Panel.brd, Qwiic Distance Sensor - VL53L1X.brd, Qwiic Distance Sensor - VL53L1X.sch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]

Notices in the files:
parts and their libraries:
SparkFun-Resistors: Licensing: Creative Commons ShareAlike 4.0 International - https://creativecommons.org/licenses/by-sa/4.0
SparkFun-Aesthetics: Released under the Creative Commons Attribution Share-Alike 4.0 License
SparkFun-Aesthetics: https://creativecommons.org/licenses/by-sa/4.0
